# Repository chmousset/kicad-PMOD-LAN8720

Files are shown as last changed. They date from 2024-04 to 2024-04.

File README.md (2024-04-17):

# PMOD-LAN8720
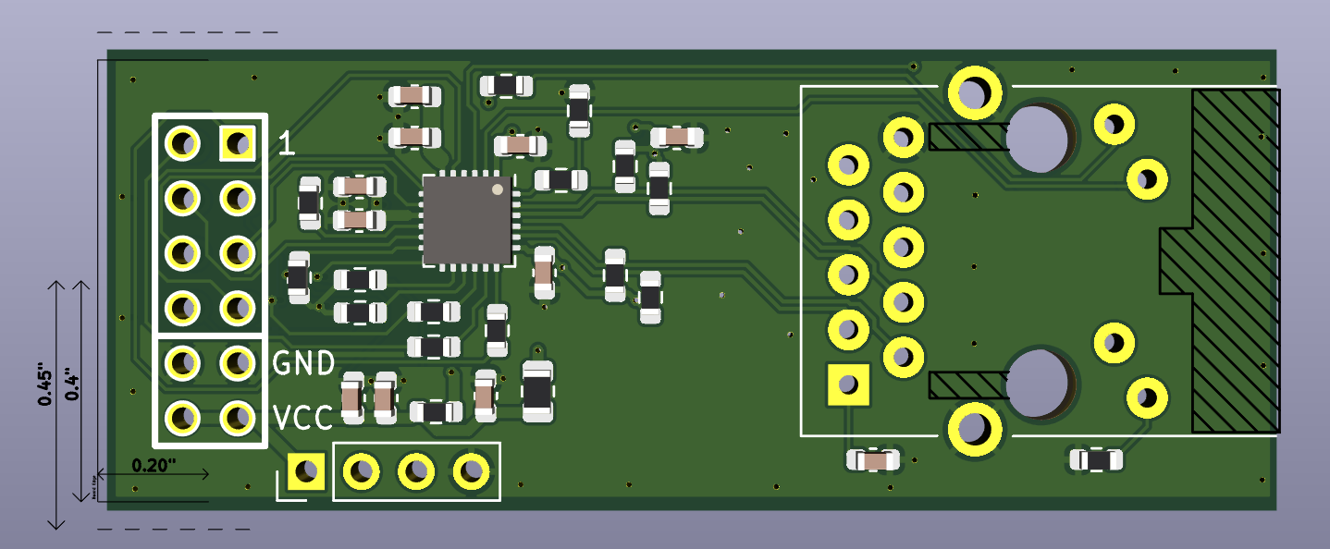
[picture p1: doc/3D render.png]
3D render 3D rendering

This is a single-width PMOD module with the RMII 10/100BASE-T PHY LAN8720. Contrary to most similar Ethernet PHY extensions, this one requires the refclk signal has to be provided from the host. It can be useful when multiple PHY have to be connected as it can reduce usage of clock-domain crossing.

## Configuration
The configuration straps are set for RMII slave operation, and link autonegociation. The MDIO is broken down on an extra connector for diagnostic or testing purposes. PHY ID 0 is used.

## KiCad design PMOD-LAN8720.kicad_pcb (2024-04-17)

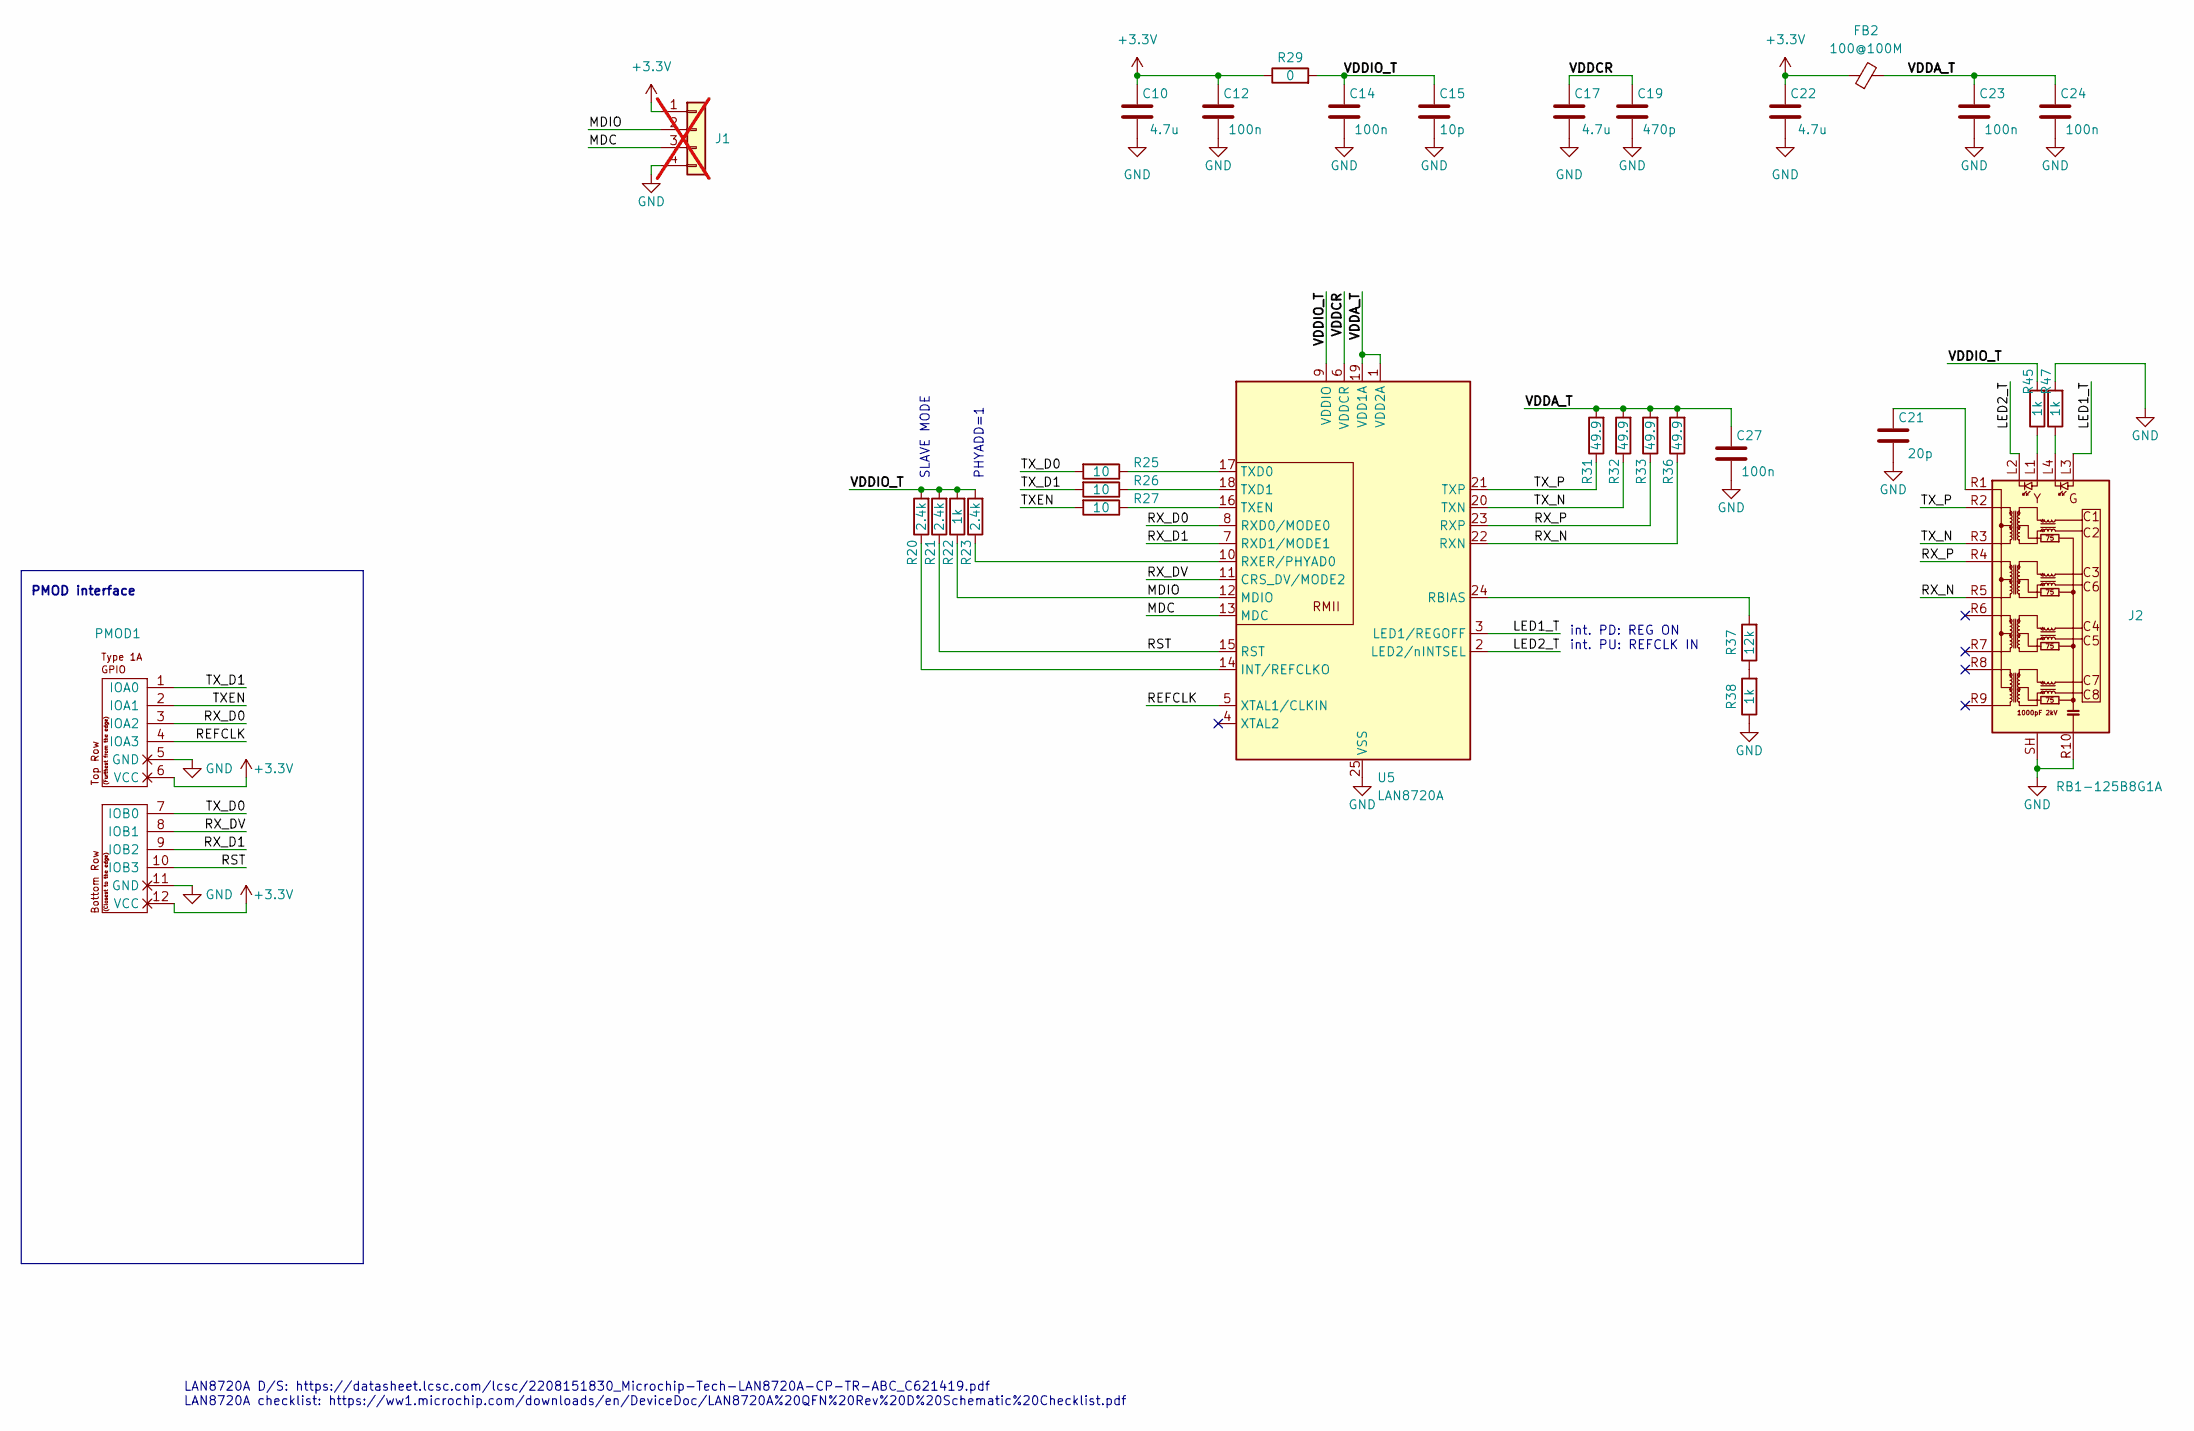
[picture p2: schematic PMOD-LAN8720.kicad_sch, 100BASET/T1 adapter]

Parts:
C10, C17, C22: 4.7u; C_0603_1608Metric; LCSC C19666
C12, C14, C23, C24, C27: 100n; C_0603_1608Metric; LCSC C14663
C15: 10p; C_0603_1608Metric; LCSC C1634
C19: 470p; C_0603_1608Metric; LCSC C1620
C21: 20p; C_0603_1608Metric; LCSC C1648
FB2: 100@100M; R_0805_2012Metric; LCSC C1015
J1: Conn_01x03; PinHeader_1x04_P2.54mm_Vertical; not fitted
J2: RB1-125B8G1A; RJ45_UDE_RB1-125B8G1A
PMOD1: PMOD-Device-x2-Type-1A-GPIO; pmod_pin_array_6x2; LCSC C492434
R20, R21, R23: 2.4k; R_0603_1608Metric; LCSC C22940
R22, R38, R45, R47: 1k; R_0603_1608Metric; LCSC C21190
R25, R26, R27: 10; R_0603_1608Metric; LCSC C22859
R29: 0; R_0603_1608Metric; LCSC C21189
R31, R32, R33, R36: 49.9; R_0603_1608Metric; LCSC C862744
R37: 12k; R_0603_1608Metric; LCSC C22790
U5: LAN8720A; QFN-24-1EP_4x4mm_P0.5mm_EP2.6x2.6mm

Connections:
+3.3V: C10.2, C12.2, C22.2, FB2.1, J1.1, PMOD1.6 (VCC), PMOD1.12 (VCC), R29.1
/LED1_T: J2.L3, U5.3 (LED1/REGOFF)
/LED2_T: J2.L2, U5.2 (LED2/nINTSEL)
/MDC: J1.3, U5.13 (MDC)
/MDIO: J1.2, R22.1, U5.12 (MDIO)
/REFCLK: PMOD1.4 (IOA3), U5.5 (XTAL1/CLKIN)
/RST: PMOD1.10 (IOB3), R21.1, U5.15 (RST)
/RX_D0: PMOD1.3 (IOA2), U5.8 (RXD0/MODE0)
/RX_D1: PMOD1.9 (IOB2), U5.7 (RXD1/MODE1)
/RX_DV: PMOD1.8 (IOB1), U5.11 (CRS_DV/MODE2)
/RX_N: J2.R5 (TD2-), R36.1, U5.22 (RXN)
/RX_P: J2.R4 (TD2+), R33.1, U5.23 (RXP)
/TXEN: PMOD1.2 (IOA1), R27.2
/TX_D0: PMOD1.7 (IOB0), R25.2
/TX_D1: PMOD1.1 (IOA0), R26.2
/TX_N: J2.R3 (TD1-), R32.1, U5.20 (TXN)
/TX_P: J2.R2 (TD1+), R31.1, U5.21 (TXP)
/VDDA_T: C23.2, C24.2, C27.2, FB2.2, R31.2, R32.2, R33.2, R36.2, U5.1 (VDD2A), U5.19 (VDD1A)
/VDDCR: C17.2, C19.2, U5.6 (VDDCR)
/VDDIO_T: C14.2, C15.2, R20.2, R21.2, R22.2, R23.2, R29.2, R45.2, U5.9 (VDDIO)
GND: C10.1, C12.1, C14.1, C15.1, C17.1, C19.1, C21.1, C22.1, C23.1, C24.1, C27.1, J1.4, J2.R10 (GND), J2.SH, PMOD1.5 (GND), PMOD1.11 (GND), R38.1, R47.2, U5.25 (VSS)
unnamed: C21.2, J2.R1 (CT)
unnamed: J2.L1, R45.1
unnamed: J2.L4, R47.1
unnamed: R37.1, R38.2
unnamed: R20.1, U5.14 (INT/REFCLKO)
unnamed: R37.2, U5.24 (RBIAS)
unnamed: R23.1, U5.10 (RXER/PHYAD0)
unnamed: R25.1, U5.17 (TXD0)
unnamed: R26.1, U5.18 (TXD1)
unnamed: R27.1, U5.16 (TXEN)

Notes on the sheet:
SLAVE MODE
LAN8720A D/S: https://datasheet.lcsc.com/lcsc/2208151830_Microchip-Tech-LAN8720A-CP-TR-ABC_C621419.pdf LAN8720A checklist: https://ww1.microchip.com/downloads/en/DeviceDoc/LAN8720A%20QFN%20Rev%20D%20Schematic%20Checklist.pdf
PHYADD=1
PMOD interface
int. PD: REG ON int. PU: REFCLK IN

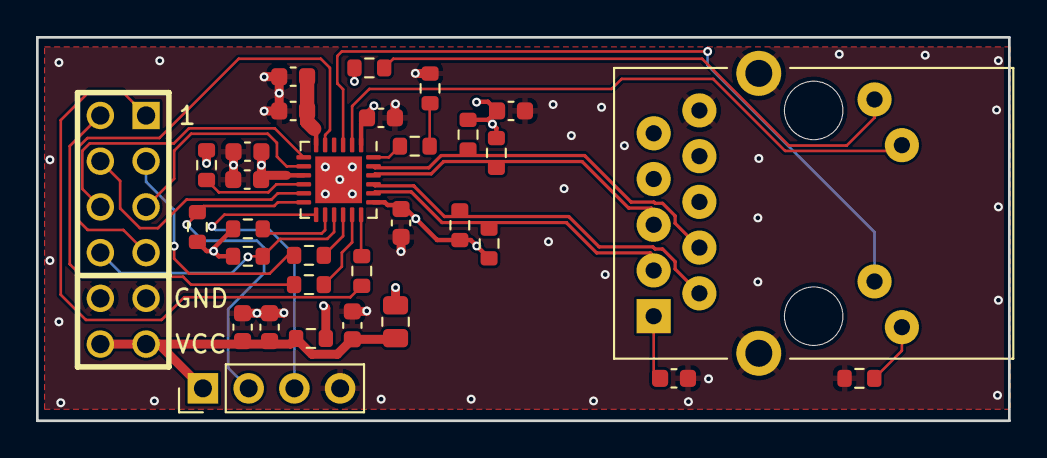
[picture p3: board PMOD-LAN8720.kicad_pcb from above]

Board: 4 copper layers, 54.0 x 21.3 mm, 32 parts (0 on the bottom side), 31 nets.
